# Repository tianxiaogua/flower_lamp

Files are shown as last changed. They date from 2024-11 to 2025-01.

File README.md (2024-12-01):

# 参考

[STM32系列(HAL库)——F103C8T6驱动WS2812全彩RGB模块（PWM+DMA方式）_stm32f1 ws2812彩虹渐变程序-CSDN博客](https://blog.csdn.net/lwb450921/article/details/124046605)

[RGB颜色查询对照表|RGB颜色|三原色配色表](https://www.sojson.com/rgb.html)

# 硬件V0.1 版本 软件首次基础代码

## 已完成

1. GPIO LED驱动正常；
2. 按键正常
3. 低功耗唤醒正常
4. 充放电正常

## 待解决
1. 修改单片机型号为STM32F103C8T6 ，原来使用的L系列芯片主频比较低，输出波形比较难达到
2. 为单片机添加外部晶振
3. 给w2812输出IO口添加上拉电阻和0R跳线电阻方便调试
4. 将工程移动到AD工程，方便后续维护；
5. 需要重新设计灯片板子和主板的挖空方式，现在的挖空不适合接线，没有注释；

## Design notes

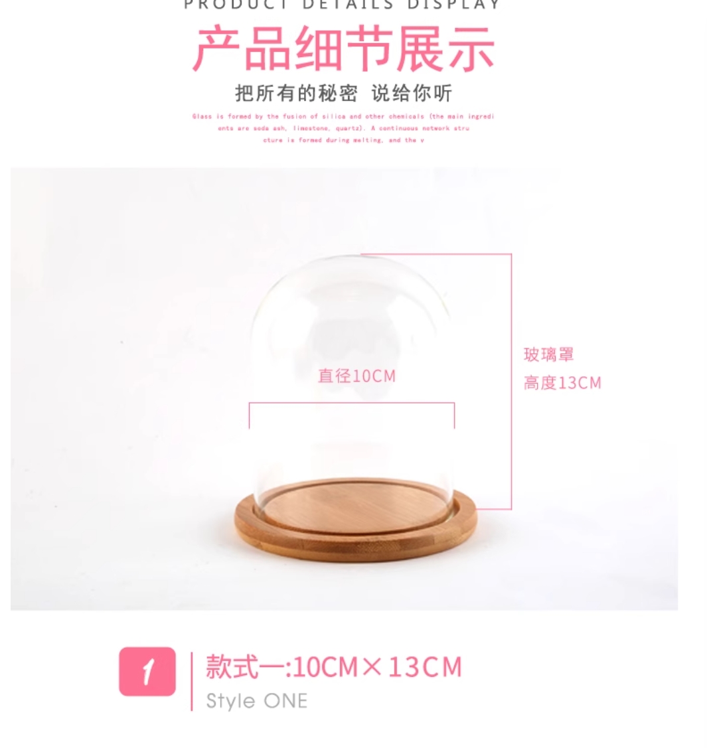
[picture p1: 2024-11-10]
3D/玻璃罩.png

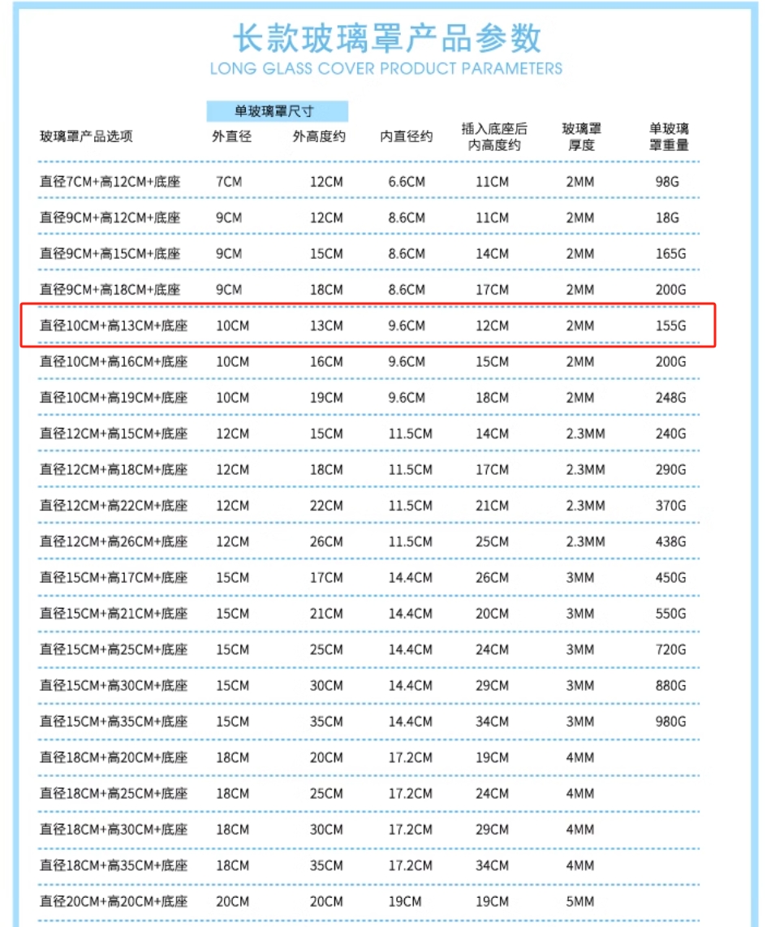
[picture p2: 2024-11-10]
3D/玻璃罩尺寸.png

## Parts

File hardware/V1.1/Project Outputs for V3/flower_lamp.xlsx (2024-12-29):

Comment | Description | Designator | Footprint | LibRef | Quantity
12pF | 0603封装的电容 | C1, C2, C7 | CC1608-0603 | Cap Chip 0603 | 3
100NF | 0603封装的电容 | C3, C4, C5, C6, C9, C11, C13 | CC1608-0603 | Cap Chip 0603 | 7
1UF | 0603封装的电容 | C8, C10, C12 | CC1608-0603 | Cap Chip 0603 | 3
100PF | 0603封装的电容 | C14 | CC1608-0603 | Cap Chip 0603 | 1
Header_6P_Curved | 弯的6P排针 | H1 | Header_2_54_6PW | Header_6P_Curved | 1
Header_2P_Curved | 弯的2P排针 | H2 | Header_2_54_2PW | Header_2P_Curved | 1
SW-TH_4P_H | 卧式轻触开关 | K1 | SW-TH_KH-6X6X7H-ZJ | SW-TH_4P_H | 1
WS2812B-2020 |  | LED1, LED2, LED3, LED4, LED5, LED6, LED7, LED8, LED9, LED10, LED11, LED12, LED13, LED14, LED15, LED16, LED17 | WS2812B-2020 | WS2812B-2020 | 17
LED 0603 |  | LED 1, LED 2 | LED 0603 | LED 0603 | 2
Header 3 | Header, 3-Pin | P1 | HDR1X3 | Header 3 | 1
SI2302 | N沟道 漏源电压(Vdss) 20V 连续漏极电流(Id) 2.8A 功率(Pd) 900mW 导通电阻(RDS(on)@Vgs,Id) 55mΩ@4.5V,2.8A 阈值电压(Vgs(th)@Id) 1.2V@250uA 输入电容(Ciss@Vds) 260pF@10V | Q1 | SOT-23 | SI2302 | 1
SI2305 | SOT-23 2.8A MOS管P沟道场效应管晶体管 | Q2 | SOT-23 | SI2305 | 1
10K | 0603封装电阻 | R1, R2, R5, R6, R8, R9, R12 | CR1608-0603 | Resistor Chip 0603 | 7
1K | 0603封装电阻 | R4, R7 | CR1608-0603 | Resistor Chip 0603 | 2
2K | 0603封装电阻 | R10, R11 | CR1608-0603 | Resistor Chip 0603 | 2
test | 测试点 | T1, T2 | test | test | 2
STM32L051C8T6 | 超低功耗单片机 | U1 | LQFP-48 | STM32L051C8T6 | 1
TP4054 | 迷你充电IC SOT-23-5 | U2 | SOT23-5 | TP4054 | 1
RT9013-33GB | LDO 2.2-5.2V IN 500Ma OUT SOT23-5 | U3 | SOT23-5 | RT9013-33GB | 1
TYPE_C_SMD_6P |  | USB1 | TYPE-C-SMD_TYPE-C-6P | TYPE_C_SMD_6P | 1
3225_8M | 3225封装的晶振 | X1 | XTAL-3225 | XTAL 3225 | 1

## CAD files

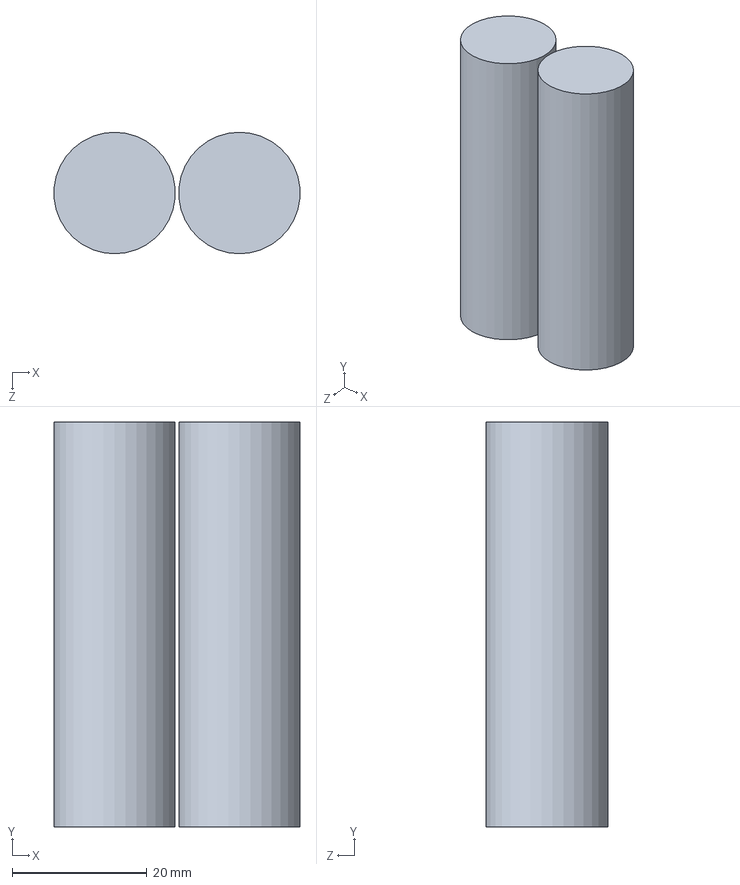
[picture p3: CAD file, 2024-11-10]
3D/电池.SLDPRT
36.4 x 60.0 x 18.0 mm

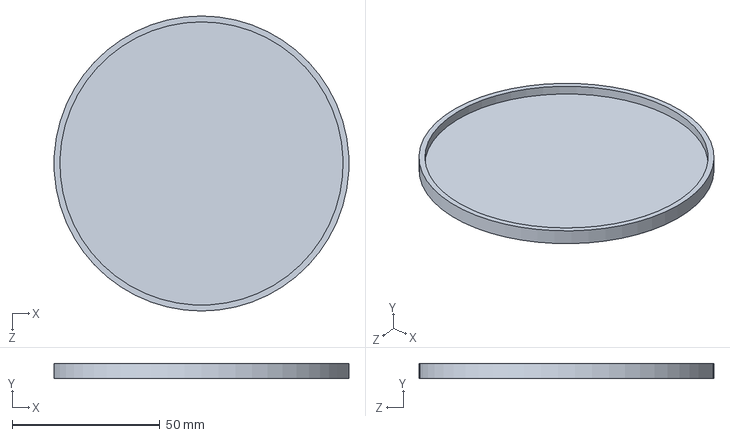
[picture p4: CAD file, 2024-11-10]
3D/底座盖.SLDPRT
99.8 x 5.00 x 100.0 mm

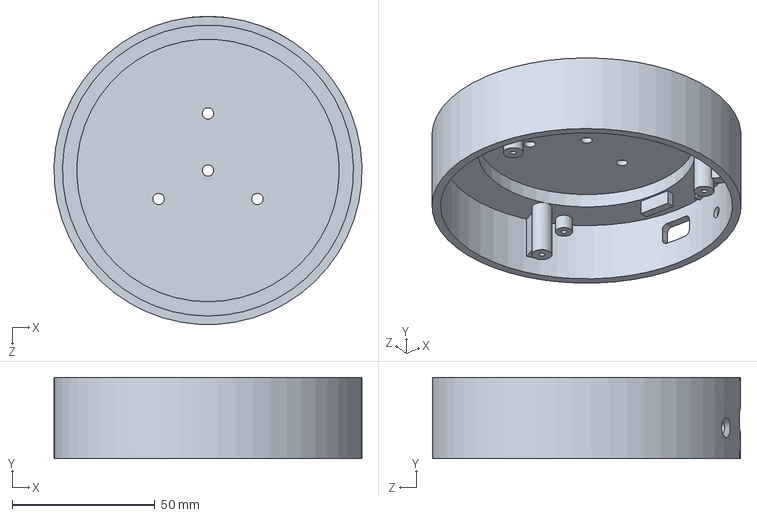
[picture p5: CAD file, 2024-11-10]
3D/底座.SLDPRT
108.0 x 28.5 x 108.0 mm

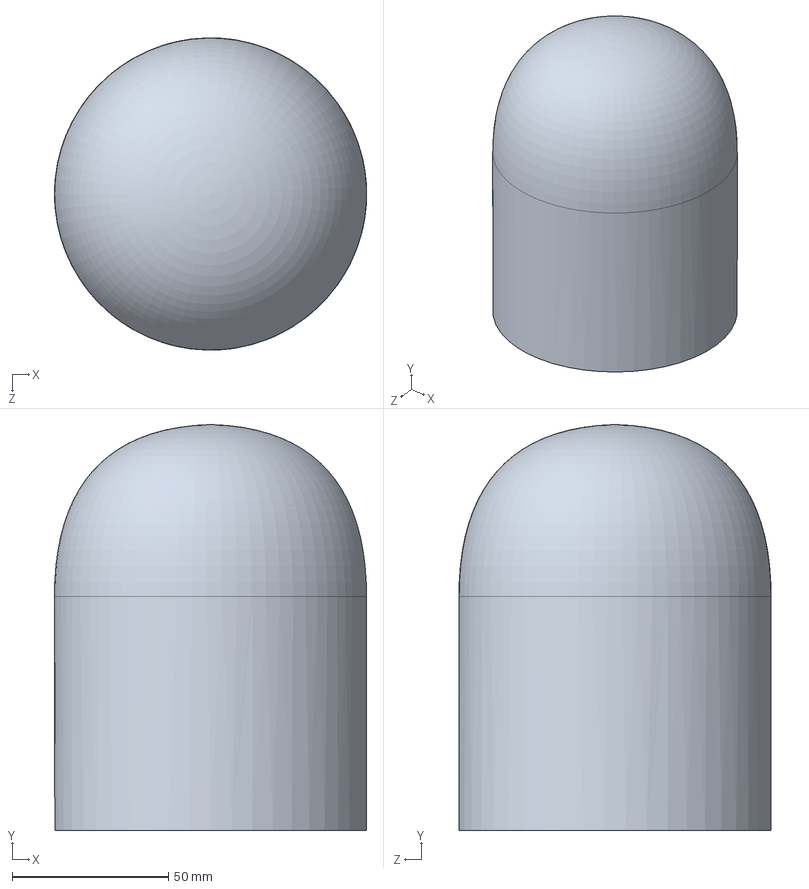
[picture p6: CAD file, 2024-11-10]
3D/玻璃罩.SLDPRT
99.9 x 130.0 x 100.0 mm

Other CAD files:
3D/底座.STL
3D/底座盖.STL

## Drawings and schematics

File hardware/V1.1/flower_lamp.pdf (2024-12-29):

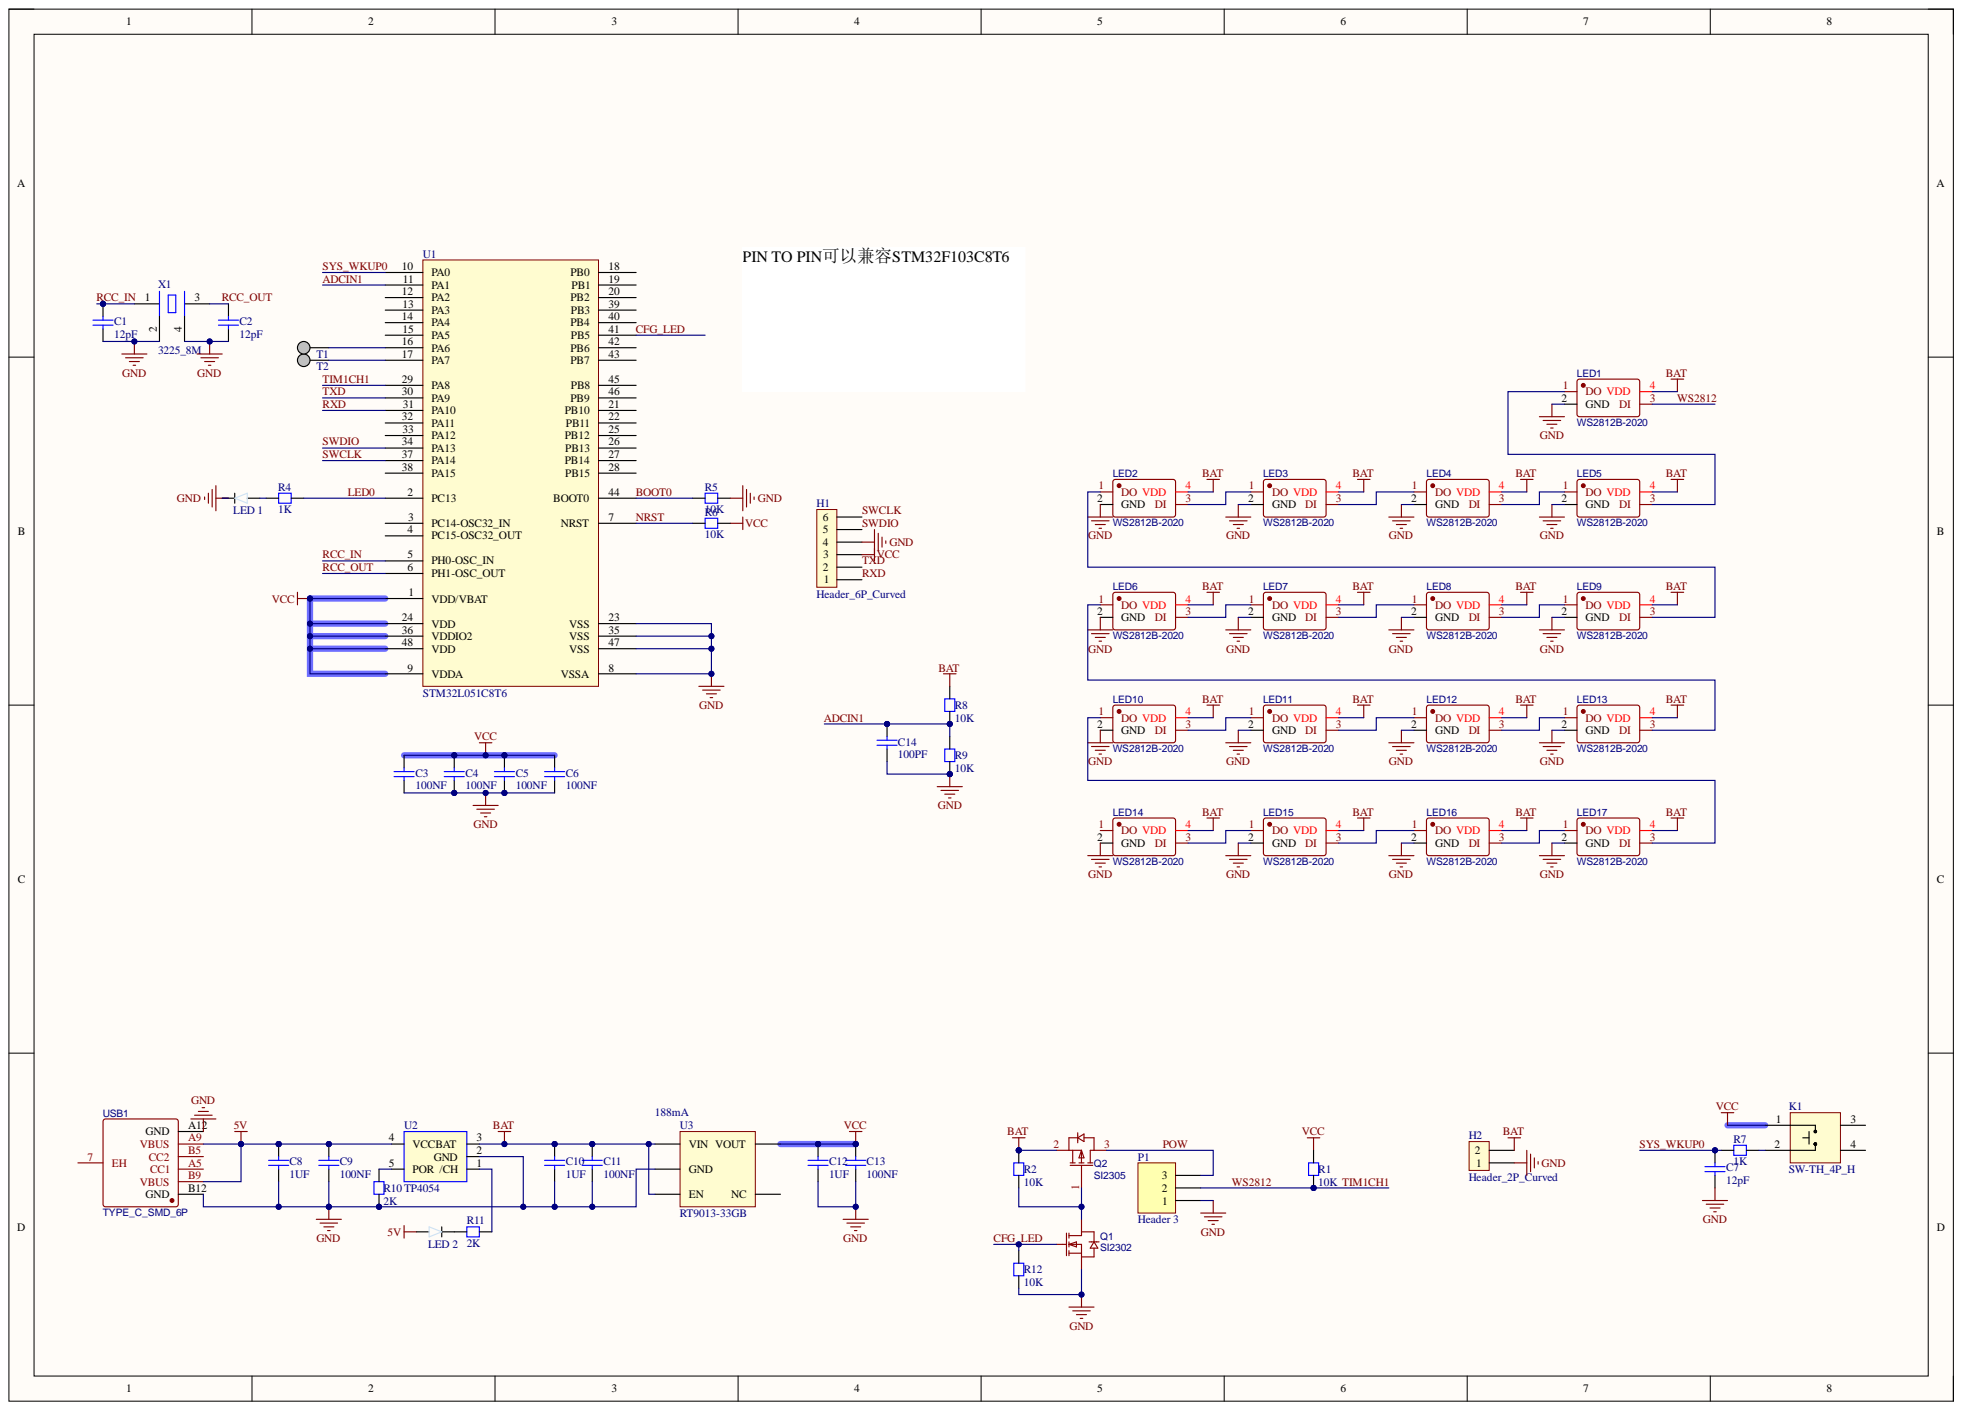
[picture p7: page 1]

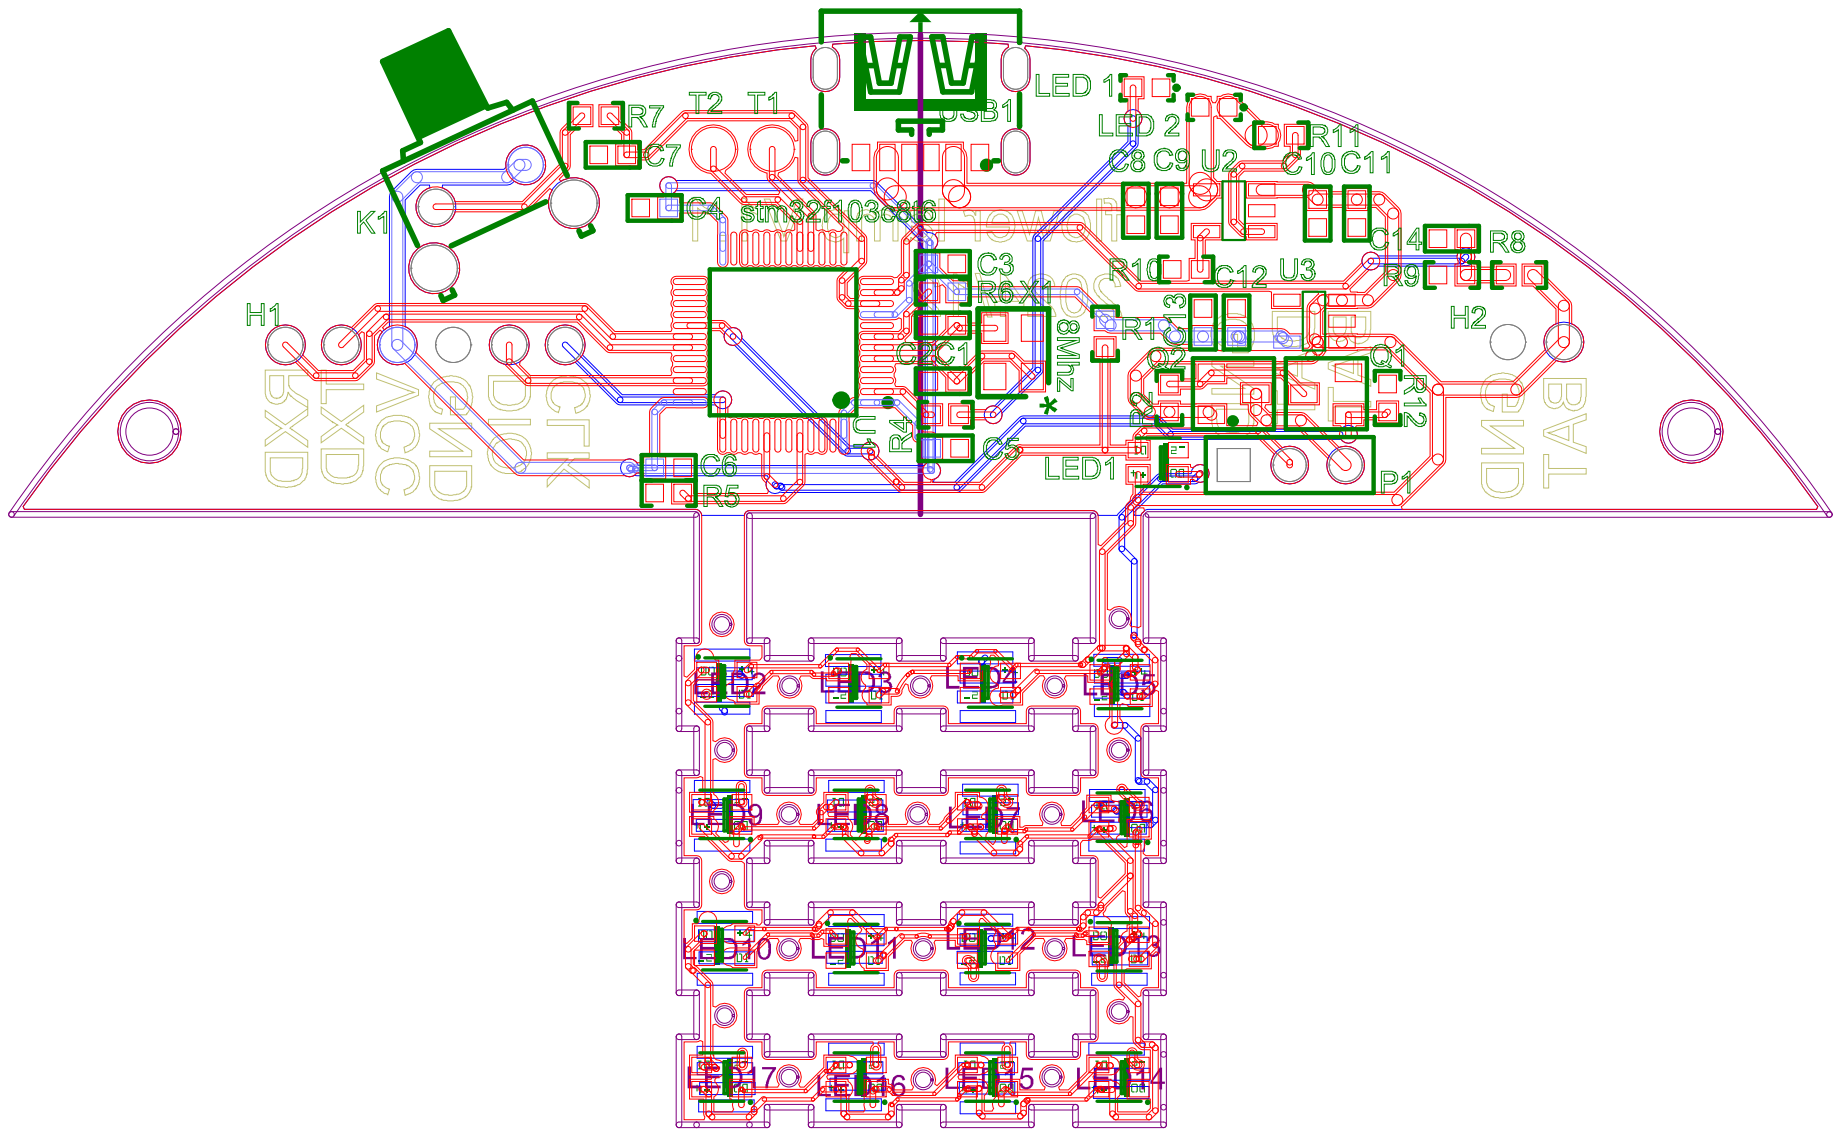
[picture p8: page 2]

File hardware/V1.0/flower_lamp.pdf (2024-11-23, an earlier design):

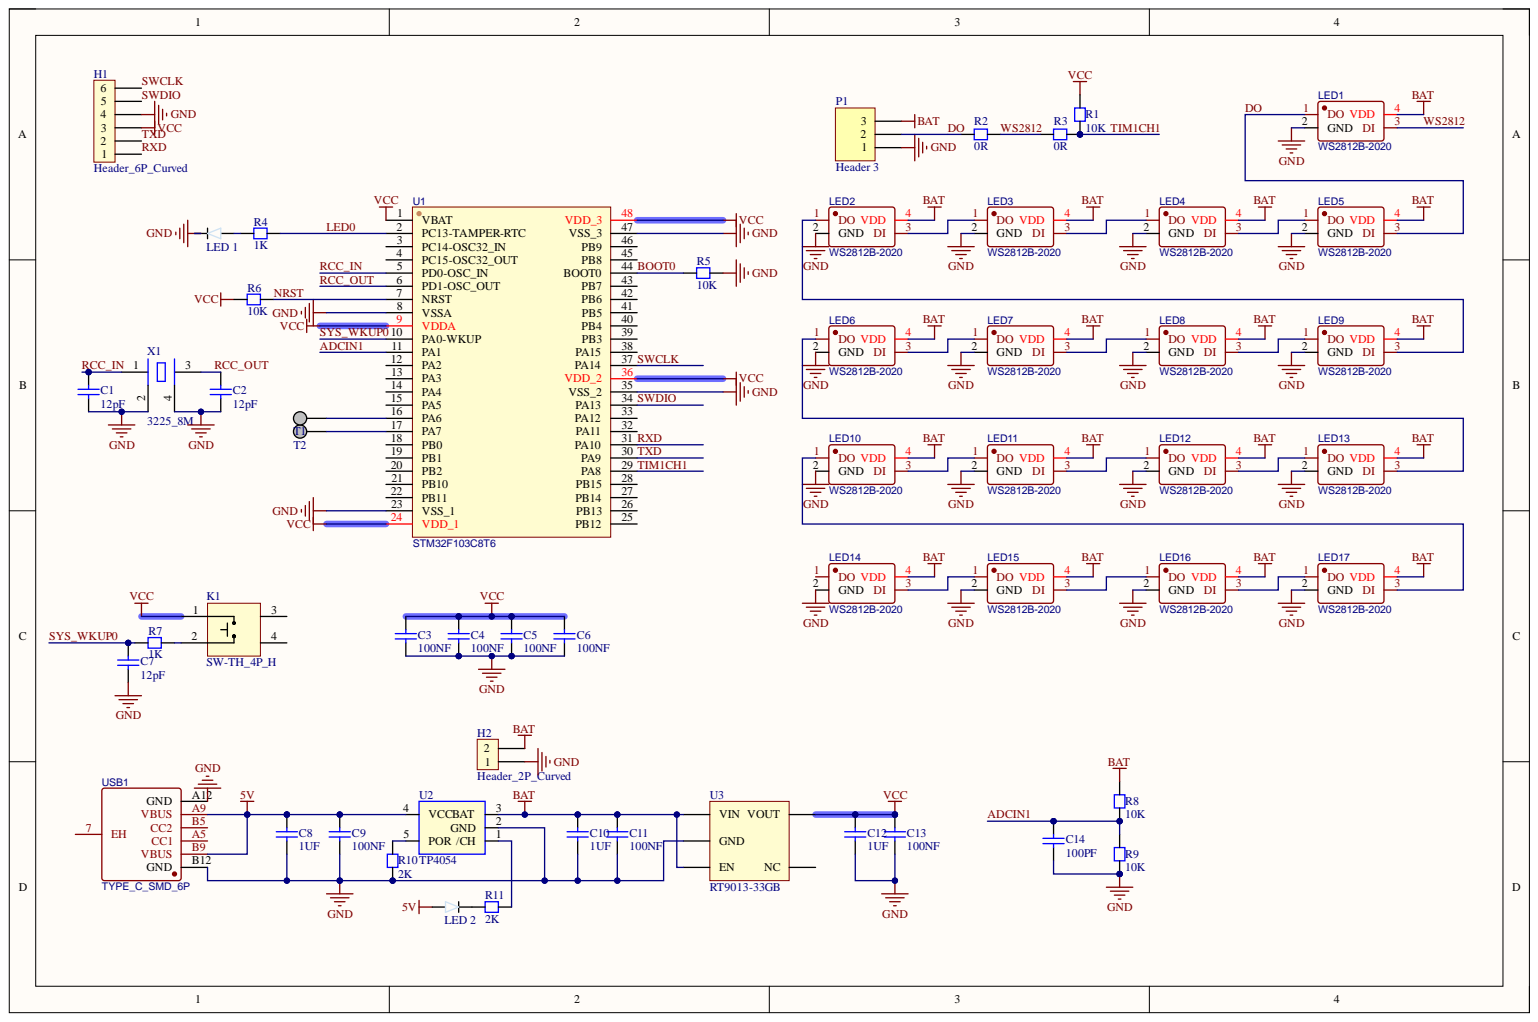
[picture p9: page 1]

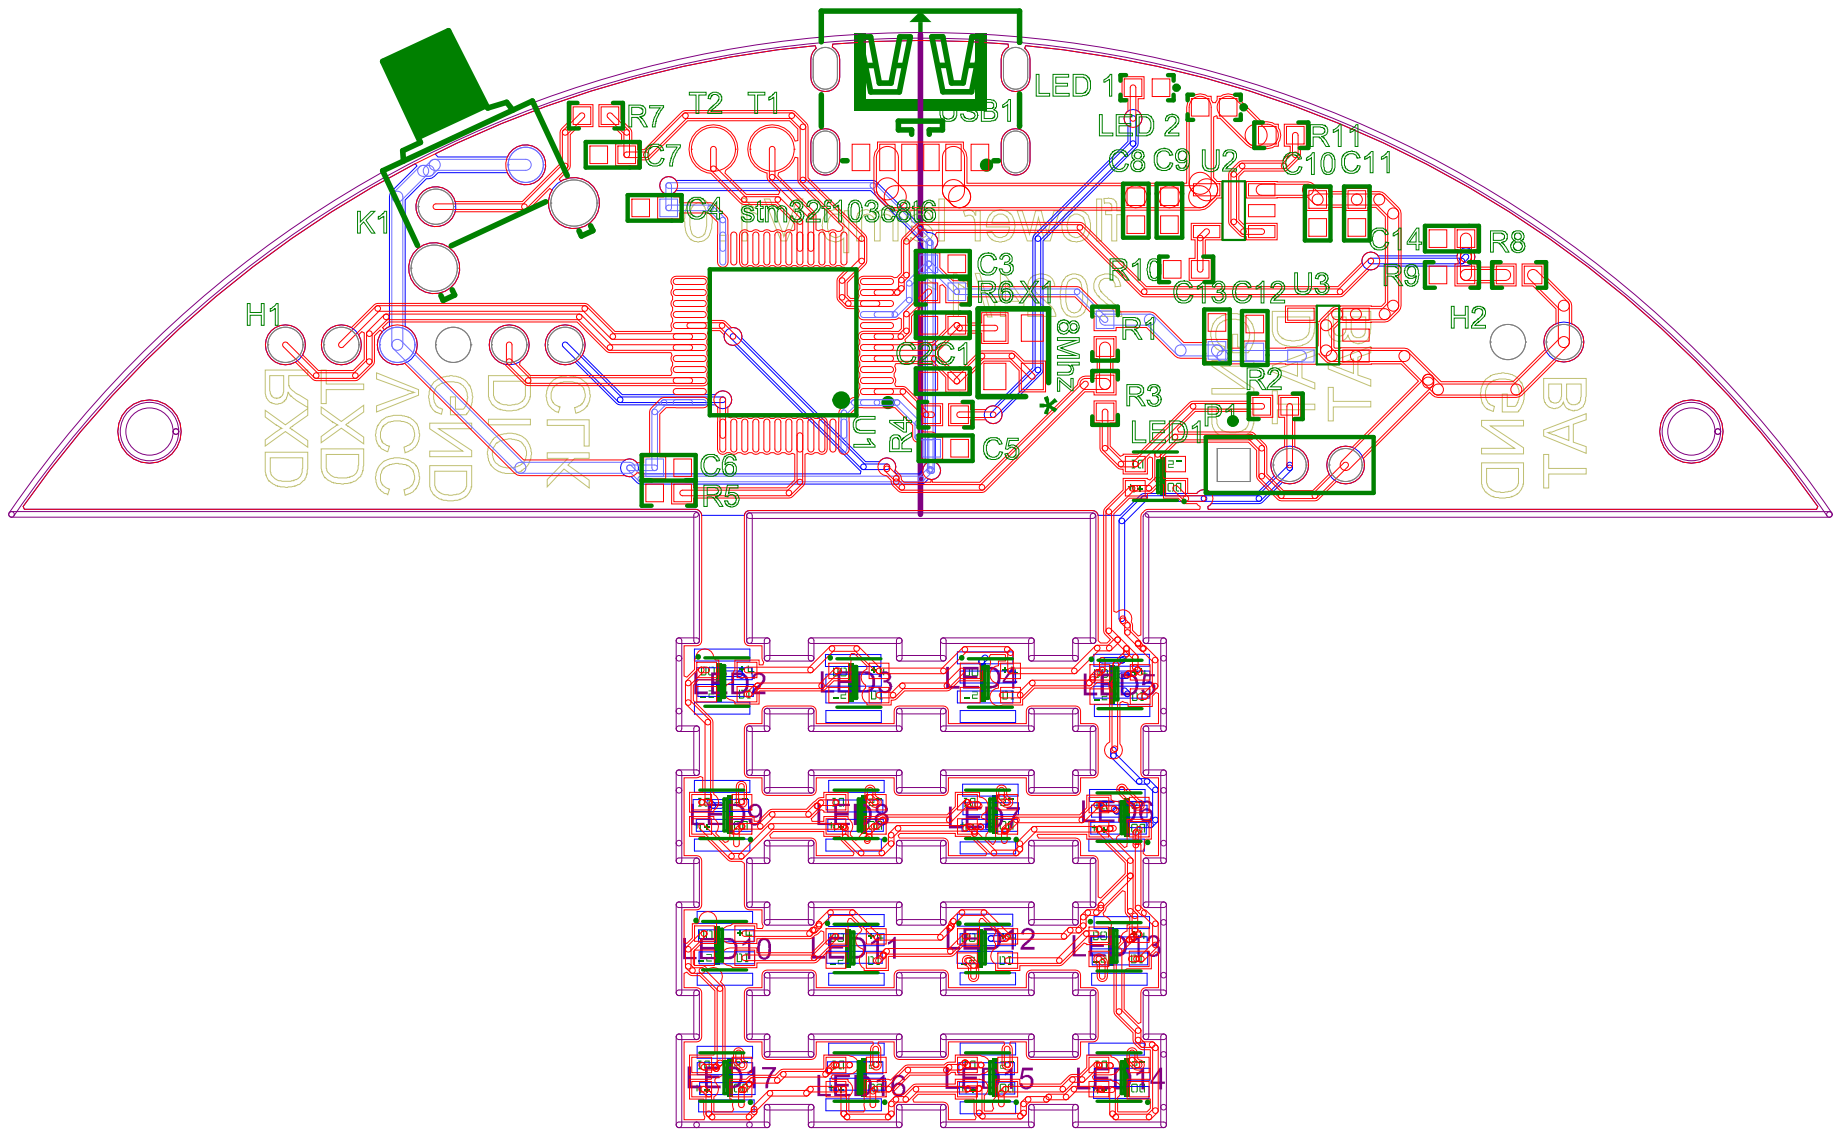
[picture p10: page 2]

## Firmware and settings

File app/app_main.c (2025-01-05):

#include "stdio.h"
#include "app_main.h"
#include "adc.h"
#include "usart.h"
#include "gpio.h"
#include "driver_tool.h"
#include "driver.h"
#include "driver_lowpower.h"
#include "RGB.h"
#include "ws2812b.h"
#include "driver_key.h"

#include<stdlib.h>

enum led_work_satus
{
	work_shutdown = 0,
	work_in
};

typedef struct
{
	uint8 led_mode;
	uint8 led_word;
	uint8 cfg_led_nums;
	uint32 time;
}APP_CTR;

typedef struct 
{
	uint8 red;
	uint8 blue;
	uint8 green;
}LED_REG;

typedef struct 
{
	uint32 led_num;
	uint32 light_time;
	uint32 off_time;
	uint32 color;
}LED_CONTROL;

LED_CONTROL g_led_ctl[17];

APP_CTR g_app_control;
KEY_PROCESS_TypeDef key_value;

// 函数：返回三个数中的最小值
int find_min(int a, int b, int c) {
    return (a < b ? (a < c ? a : c) : (b < c ? b : c));
}
// 函数：返回三个数中的中间值
int find_middle(int a, int b, int c) {
    return (a >= b ? (a <= c ? a : (b >= c ? b : c)) : (a >= c ? a : (b <= c ? b : c)));
}
// 函数：返回三个数中的最大值
int find_max(int a, int b, int c) {
    return (a >= b ? (a >= c ? a : c) : (b >= c ? b : c));
}

uint32 get_rand(uint32 seed, uint32 rand_max, uint32 rand_min)
{
	// srand(g_app_control.time);
	return rand() % (rand_max + 1 - rand_min) + rand_min;//随机数生成
}


int32 led_delay(int32 ms)
{
	for (int i=0; i<ms; i++) {
		if (g_app_control.led_word == work_in) {
			delay_ms(1);
		} else {
			return REV_ERR;
		}
	}
	return REV_OK;
}


void light_clean()
{
	for(int i=0;i<17;i++) {
		WS2812b_Set(i,0,0,0);
	}
}


void get_reg_data(uint32 color, LED_REG *data)
{
	data->red = color>>16;
	data->green = color>>8 & 0xFF00FF;
	data->blue = color & 0x0000FF;
}

void set_led_color(uint32 num, uint32 color)
{
	LED_REG data;
	get_reg_data(color, &data);
	WS2812b_Set(num,data.red, data.green, data.blue);
}


void light_mode7(uint32 color)
{
	while (1) {
		for (int i=0; i<g_app_control.cfg_led_nums; i++) {
			set_led_color(i, color);
		}
		if (led_delay(10000) == REV_ERR) return;
	}
}


void light_mode4()
{
	uint32 ligth_time = 0;
	uint32 all_time = 10*1000;
	uint32 all_color = 450;

	srand(g_app_control.time);

	for (int i=0; i<g_app_control.cfg_led_nums; i++) {
		g_led_ctl[i].led_num = i;
		g_led_ctl[i].color = RGB_16[get_rand(g_app_control.time, all_color, 0)];
		g_led_ctl[i].light_time = get_rand(g_app_control.time, all_time, 0);
		g_led_ctl[i].off_time = g_led_ctl[i].light_time + 3000;
		GUA_LOGI("color:%d begin:%d end:%d", g_led_ctl[i].color, g_led_ctl[i].light_time, g_led_ctl[i].off_time);
	}

	while (1) {
		for (int i=0; i<g_app_control.cfg_led_nums; i++) {
			if (g_led_ctl[i].light_time == ligth_time) {
				set_led_color(g_led_ctl[i].led_num, g_led_ctl[i].color);
			}
			if (g_led_ctl[i].off_time == ligth_time) {
				set_led_color(g_led_ctl[i].led_num, 0x000000); // 熄灭
			}
		}

		ligth_time++;
		if (ligth_time > all_time) { // 10秒钟
			ligth_time = 0;

			for (int i=0; i<g_app_control.cfg_led_nums; i++) {
				g_led_ctl[i].led_num = i;
				g_led_ctl[i].color = RGB_16[get_rand(g_app_control.time, all_color, 0)];
				g_led_ctl[i].light_time = get_rand(g_app_control.time, all_time, 0);
				g_led_ctl[i].off_time = g_led_ctl[i].light_time + 1000;
				GUA_LOGI("color:%d begin:%d end:%d", g_led_ctl[i].color, g_led_ctl[i].light_time, g_led_ctl[i].off_time);
			}
		}
		if (led_delay(1) == REV_ERR) return;
	}
}


void light_mode3(uint32 color)
{
	uint32 ligth_time = 0;
	uint32 all_time = 10*1000;
	srand(g_app_control.time);

	for (int i=0; i<g_app_control.cfg_led_nums; i++) {
		g_led_ctl[i].led_num = i;
		g_led_ctl[i].color = color;
		g_led_ctl[i].light_time = get_rand(g_app_control.time, all_time, 0);
		g_led_ctl[i].off_time = g_led_ctl[i].light_time + 3000;
		GUA_LOGI("color:%d begin:%d end:%d", g_led_ctl[i].color, g_led_ctl[i].light_time, g_led_ctl[i].off_time);
	}

	while (1) {
		for (int i=0; i<g_app_control.cfg_led_nums; i++) {
			if (g_led_ctl[i].light_time == ligth_time) {
				set_led_color(g_led_ctl[i].led_num, g_led_ctl[i].color);
			}
			if (g_led_ctl[i].off_time == ligth_time) {
				set_led_color(g_led_ctl[i].led_num, 0x000000); // 熄灭
			}
		}

		ligth_time++;
		if (ligth_time > all_time) { // 10秒钟
			ligth_time = 0;

			for (int i=0; i<g_app_control.cfg_led_nums; i++) {
				g_led_ctl[i].led_num = i;
				g_led_ctl[i].color = color;
				g_led_ctl[i].light_time = get_rand(g_app_control.time, all_time, 0);
				g_led_ctl[i].off_time = g_led_ctl[i].light_time + 1000;
				GUA_LOGI("color:%d begin:%d end:%d", g_led_ctl[i].color, g_led_ctl[i].light_time, g_led_ctl[i].off_time);
			}
		}

		if (led_delay(1) == REV_ERR) return;
	}
}

void light_mode1()
{
	uint32 led_1, led_2, led_3; 
	uint8 led_display1[20], led_display2[20], led_display3[20];

	srand(g_app_control.time);
	while (1) {
		led_1 = get_rand(g_app_control.time, 131072, 0);// * 4096;
		for (int i=g_app_control.cfg_led_nums; i>=0; i--) {
			led_display1[i] =  (led_1 >> i) & 1;
		}
		
		led_2 = get_rand(g_app_control.time, 131072, 0);// * 4096;
		for (int i=g_app_control.cfg_led_nums; i>0; i--) {
			led_display2[i] =  (led_2 >> i) & 1;
		}
		led_3 = get_rand(g_app_control.time, 131072, 0);// * 4096;
		for (int i=g_app_control.cfg_led_nums; i>0; i--) {
			led_display3[i] =  (led_3 >> i) & 1;
		}
		// GUA_LOGI("led_display:%d %d %d", led_1, led_2, led_3);

		for(int i=0;i<17;i++) {
			if (led_display1[i])
				WS2812b_Set(i,0,20,0);
			else 
				WS2812b_Set(i,0,0,0);
		}
		
		if (led_delay(300) == REV_ERR) return;

		for(int i=0;i<17;i++) {
			if (led_display2[i]) 
				WS2812b_Set(i,0,0,20);
			else 
				WS2812b_Set(i,0,0,0);
		}
		if (led_delay(300) == REV_ERR) return;

		for(int i=0;i<17;i++) {
			if (led_display3[i]) 
				WS2812b_Set(i,20,0,0);
			else 
				WS2812b_Set(i,0,0,0);
		}
		if (led_delay(300) == REV_ERR) return;
	}
}


void light_mode2()
{
	uint32 clolor = 0x0F0F0F;
	LED_REG led_rgb;
	get_reg_data(clolor, &led_rgb);
	uint8 min_value = find_min(led_rgb.red, led_rgb.green, led_rgb.blue);
	uint8 middle_value = find_middle(led_rgb.red, led_rgb.green, led_rgb.blue);
	uint8 max_value = find_max(led_rgb.red, led_rgb.green, led_rgb.blue);

	GUA_LOGI("min_value %d middle_value %d max_value %d", min_value, middle_value, max_value);
	
	while (1)
	{
		for (int i=0; i<=min_value; i++) {
			for(int j=0; j<17; j++) {
				WS2812b_Set(j, i,  i, i);
			}
			if (led_delay(80) == REV_ERR) return;
		}
		
		for (int i=0; i<=min_value; i++) {
			for(int j=0; j<17; j++) {
				WS2812b_Set(j,led_rgb.red-i,led_rgb.green-i,led_rgb.blue-i);
			}
			if (led_delay(80) == REV_ERR) return;
		}
	}
}


void led_task(void)
{
	while (1) {
		g_app_control.led_word = work_in;
		switch (g_app_control.led_mode) {
			case 0: light_mode2(); break;
			case 1: light_mode4(); break;
			case 2: light_mode3(0x0F0F01); break;
			case 3: light_mode3(0xA52A2A); break;
			case 4: light_mode3(0x0F0F0F); break;
			case 5: light_mode1(); break;

			// 连按两次展示常亮灯效
			case 8: light_mode7(0xF09F01); break;
			case 7: light_mode7(0xFFFFFF); break;
			default: break;
		}
		light_clean();
		led_delay(10);
	}
}

void task_main(void)
{
	uint8 histery_key = 0, key =0;
	uint8 key_sta;
	uint8 led_status = 0;
	float data_voltage_buf[10] = {0};
	int32 rev = 0;
	float data_average = 0;

	memset(&g_app_control, 0, sizeof(APP_CTR));
	g_app_control.cfg_led_nums = 17;

	key_config_init(&key_value);
    driver_init();
	WS2812b_Init();
    driver_register_delay_ms(osDelay);

	#if !TEST
	for (int i=0; i<10; i++) {
		data_voltage_buf[i] = get_voltage();
		GUA_LOGW("time:%d get voltage = %.2fV", i, data_voltage_buf[i]);
		delay_ms(10);
	}
    rev = driver_remove_max_and_min(data_voltage_buf, sizeof(data_voltage_buf)/sizeof(float));
	for (int i=0; i<rev; i++) {
		data_average += data_voltage_buf[i];
	}
	data_average = data_average/rev;

	GUA_LOGW("voltage = %.2fV", data_average);

    if (data_average < LOW_POWER_VOLTAGE) {
        GUA_LOGW("lowpower sleep!");
        set_lowpower_sleep();
        return;
    }
	#endif
    init_lowpower();
    init_gpio();
    WS2812b_Init();
	HAL_GPIO_WritePin(LED0_GPIO_Port, LED0_Pin, GPIO_PIN_SET);

	// for (int i=0; i<17; i++) {
	// 	set_led_color(i, 0xF09F01);
	// } while (1);

    GUA_LOGI("class begin");
    while (1)
    {
		key = get_key();
		if (key == 1) {
			if (histery_key != key) {
				key_value.flag.key_state = KEY_STATE_PRESS;	//按下
				key_value.flag.check = 1;
				key_value.time_continus = 0;		//按键持续时间置零，准备开始计时
				histery_key = key;
			}
		} else {
			if (histery_key != key) {
				key_value.flag.key_state = KEY_STATE_RELEASE;	//松开
				key_value.flag.check = 1;
				key_value.time_idle = 0;			//按键空闲时间置零，准备开始计时
				histery_key = key;
			}
		}
		key_Process(&key_value);
		key_sta = key_scan(&key_value);
		delay_ms(10);

		// 键值处理
		if (key_sta == EVENT_SHORT_CLICK) {
			g_app_control.led_word = work_shutdown;
			g_app_control.led_mode++;
			if(g_app_control.led_mode > 5){
				g_app_control.led_mode = 0;
			}
			GUA_LOGI("led_mode %d", g_app_control.led_mode);
		}

		if (key_sta == EVENT_DOUBLE_CLICK) {
			if (key_value.press_cnt == 2) { // 连按2次
				GUA_LOGE("go to led long mode");
				led_status++;
				if (led_status > 2) {
					led_status = 1;
				}
				g_app_control.led_word = work_shutdown;
				switch (led_status) {
					case 1: g_app_control.led_mode = 7; break;
					case 2: g_app_control.led_mode = 8; break;
					default: break;
				}
			}
		
		}

		if (key_sta == EVENT_LONG_CLICK) {
			GUA_LOGE("sleep");
			HAL_GPIO_WritePin(LED0_GPIO_Port, LED0_Pin, GPIO_PIN_RESET);
			light_clean();
			set_lowpower_sleep();
			delay_ms(3000);
		}

		g_app_control.time++;
		if (g_app_control.time > 10000000) {
			g_app_control.time = 0;
		}
    }
}

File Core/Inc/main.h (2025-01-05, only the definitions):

#define LED0_Pin GPIO_PIN_13
#define LED0_GPIO_Port GPIOC
#define CFG_LED_Pin GPIO_PIN_5
#define CFG_LED_GPIO_Port GPIOB

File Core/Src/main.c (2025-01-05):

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
/* Includes ------------------------------------------------------------------*/
#include "main.h"
#include "cmsis_os.h"
#include "adc.h"
#include "dma.h"
#include "spi.h"
#include "tim.h"
#include "usart.h"
#include "gpio.h"

/* USER CODE BEGIN Includes */
#include "RGB.h"
#include "ws2812b.h"
#include "app_main.h"
#include "device_usart.h"
/* USER CODE END Includes */


void SystemClock_Config(void);
void MX_FREERTOS_Init(void);
/**
  * @brief  The application entry point.
  * @retval int
  */
int main(void)
{
  /* MCU Configuration--------------------------------------------------------*/

  /* Reset of all peripherals, Initializes the Flash interface and the Systick. */
  HAL_Init();

  /* Configure the system clock */
  SystemClock_Config();

  /* Initialize all configured peripherals */
  MX_GPIO_Init();
  MX_DMA_Init();
  MX_TIM1_Init();
  MX_ADC1_Init();
  MX_SPI1_Init();
  MX_USART1_UART_Init();
  /* USER CODE BEGIN 2 */
//	task_main();
  /* USER CODE END 2 */

  /* Call init function for freertos objects (in freertos.c) */
  MX_FREERTOS_Init();

  /* Start scheduler */
  osKernelStart();
  /* We should never get here as control is now taken by the scheduler */
  /* Infinite loop */
  /* USER CODE BEGIN WHILE */
  while (1)
  {
    /* USER CODE END WHILE */

    /* USER CODE BEGIN 3 */
		for(int i=0;i<17;i++)
		{
			WS2812b_Set(i,0,20,0);
		}
		HAL_Delay(600);
		for(int i=0;i<17;i++)
		{
			WS2812b_Set(i,20,0,0);
		}
		HAL_Delay(600);
		for(int i=0;i<17;i++)
		{
			WS2812b_Set(i,0,0,20);
		}
		HAL_Delay(600);
		}
  /* USER CODE END 3 */
}

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
/**
  * @brief  Period elapsed callback in non blocking mode
  * @note   This function is called  when TIM2 interrupt took place, inside
  * HAL_TIM_IRQHandler(). It makes a direct call to HAL_IncTick() to increment
  * a global variable "uwTick" used as application time base.
  * @param  htim : TIM handle
  * @retval None
  */
void HAL_TIM_PeriodElapsedCallback(TIM_HandleTypeDef *htim)
{
  if (htim->Instance == TIM2) {
    HAL_IncTick();
  }
}

/**
  * @brief  This function is executed in case of error occurrence.
  * @retval None
  */
void Error_Handler(void)
{
  /* USER CODE BEGIN Error_Handler_Debug */
  /* User can add his own implementation to report the HAL error return state */
  __disable_irq();
  while (1)
  {
  }
  /* USER CODE END Error_Handler_Debug */
}

#ifdef  USE_FULL_ASSERT
/**
  * @brief  Reports the name of the source file and the source line number
  *         where the assert_param error has occurred.
  * @param  file: pointer to the source file name
  * @param  line: assert_param error line source number
  * @retval None
  */
void assert_failed(uint8_t *file, uint32_t line)
{
  /* USER CODE BEGIN 6 */
  /* User can add his own implementation to report the file name and line number,
     ex: printf("Wrong parameters value: file %s on line %d\r\n", file, line) */
  /* USER CODE END 6 */
}
#endif /* USE_FULL_ASSERT */

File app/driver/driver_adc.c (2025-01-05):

#include "driver_adc.h"
#include "adc.h"
#include "usart.h"
#include "gpio.h"
#include "driver_tool.h"

uint32_t driver_adc()
{
	HAL_ADC_Start(&hadc1);    //启动ADC转换
	HAL_ADC_PollForConversion(&hadc1,1); //等待转换完成，10ms表示超时时间
	uint32_t AD_Value = HAL_ADC_GetValue(&hadc1);  //读取ADC转换数据（12位数据）
	//printf("ADC1_IN1 ADC value: %d\r\n",AD_Value);
	float Vol_Value = AD_Value*(3.3/4096);  //AD值乘以分辨率即为电压值
	//printf("ADC1_IN1 VOL value: %.2fV\r\n",Vol_Value);
	return 1;
}


//获取电压
float get_voltage(void)
{
	HAL_ADC_Start(&hadc1);    //启动ADC转换
	HAL_ADC_PollForConversion(&hadc1,1); //等待转换完成，10ms表示超时时间
	uint32_t AD_Value = HAL_ADC_GetValue(&hadc1);  //读取ADC转换数据（12位数据）
	printf("V:%03f\r\n", AD_Value*(3.3/4096));
	float Vol_Value = AD_Value*(3.3/4096)*2;  //AD值乘以分辨率即为电压值
	return Vol_Value;
}

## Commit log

2024-11-10 首次更新1、首版3D结构件和采购件；2、首版V0.1硬件；3、软件完成LED灯闪烁；4、更新readme文件；4、更新cubemx配置；
    [底座.SLDPRT, 底座.STL, 底座盖.SLDPRT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]
2024-11-10 完成GPIO驱动，adc电池电量检测，低功耗睡眠唤醒，驱动移植等
2024-11-22 更新硬件
    [PCB.PcbDoc, Sheet1.SchDoc, flower_lamp.PrjPcb]
2024-12-01 完成ws2812驱动，更换单片机
    [RGB对照表.xlsx]
2024-12-02 新增操作系统，新增按键检测
2024-12-05 更新显示方法
2024-12-06 更新亮灯模式，随机亮灯，迭代PCB版本
    [PCB.PcbDoc, Sheet1.SchDoc, flower_lamp.PrjPcb]
2024-12-07 完成灯效设计和低功耗处理，发布V1.1版本PCb
    [PCB.PcbDoc, flower_lamp.PrjPcb]
2024-12-29 更换mos管开关用于驱动LED
    [PCB.PcbDoc, Sheet1.SchDoc, flower_lamp.xlsx]
2025-01-05 完成全部驱动，功耗调整至200uA
    [PCB.PcbDoc]

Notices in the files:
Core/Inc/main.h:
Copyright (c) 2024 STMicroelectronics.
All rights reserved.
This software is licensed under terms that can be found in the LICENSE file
